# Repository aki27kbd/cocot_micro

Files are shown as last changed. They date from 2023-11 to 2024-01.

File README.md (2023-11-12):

# cocot_micro

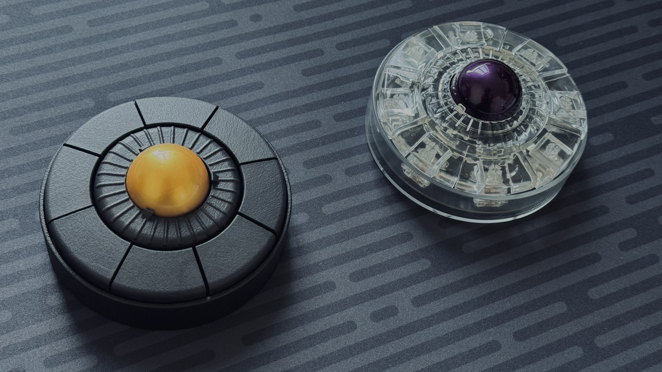
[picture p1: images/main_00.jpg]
cocot_micro_main00


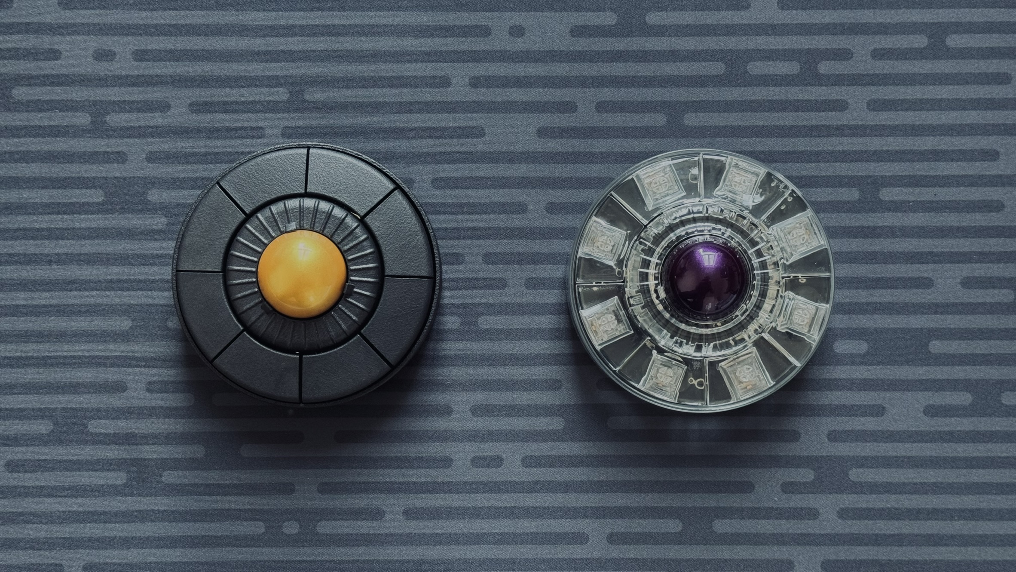
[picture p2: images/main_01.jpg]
cocot_micro_main01


cocot micro is a DIY trackball composed of mechanical keyboard components. You can use it as a trackball mouse as well as a macro pad with a pointing device.

### Features
- Customizable 8 buttons like mouse left/center/right clicks or any other keycodes
- Symmetrical design which enables you to use either right/left hands you prefer to
- With a ring encoder around the ball, you can assign keys like volume up/down or scroll up/down
- Smooth bearing rollers supports the ball
- You can swap a 34mm ball with a 40mm ball with optional ball base/ballcover parts
- With vial-compatible firmware, you can easily customize your own keymaps
- The center of PCB can be cut off and used for a MCU & sensor module with which you can create your own trackball mouse

### Configuration
- Keyboard Maintainer: [aki27kbd](https://github.com/aki27kbd) [@aki27kbd](https://twitter.com/aki27kbd)
- Hardware Supported: cocot micro PCB, RP2040 on board
- Hardware Availability: [cocotkeebs](https://cocotkeebs.com)

Build Guide [JP](doc/buildguide.md) / [EN](doc/buildguide_en.md)

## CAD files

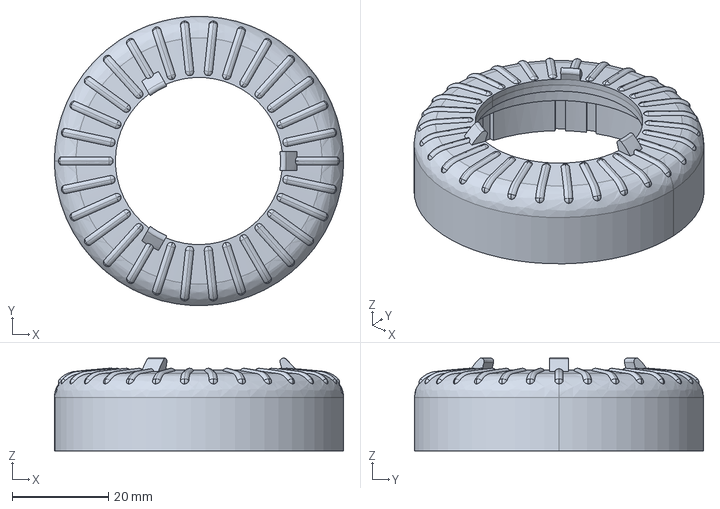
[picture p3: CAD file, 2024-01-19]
hardware/cocot_micro_BallCover_34mm_ClearResin.stp
60.0 x 59.9 x 19.2 mm

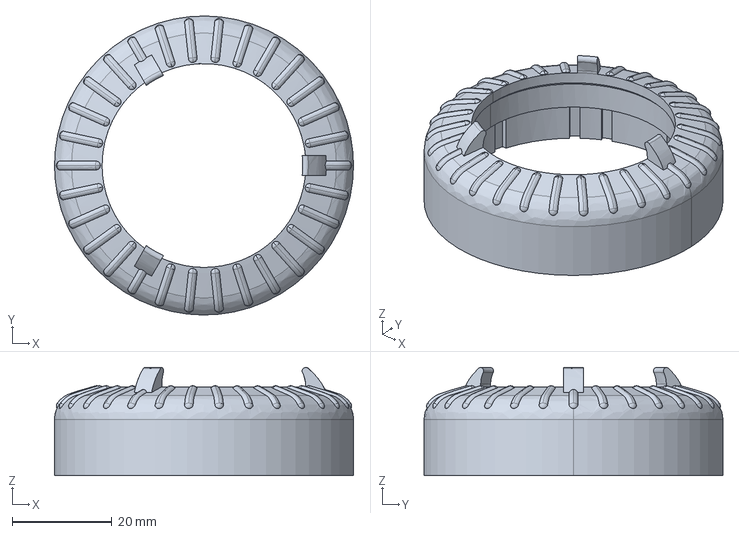
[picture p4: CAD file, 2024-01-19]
hardware/cocot_micro_BallCover_40mm_ClearResin.stp
60.0 x 60.0 x 21.7 mm

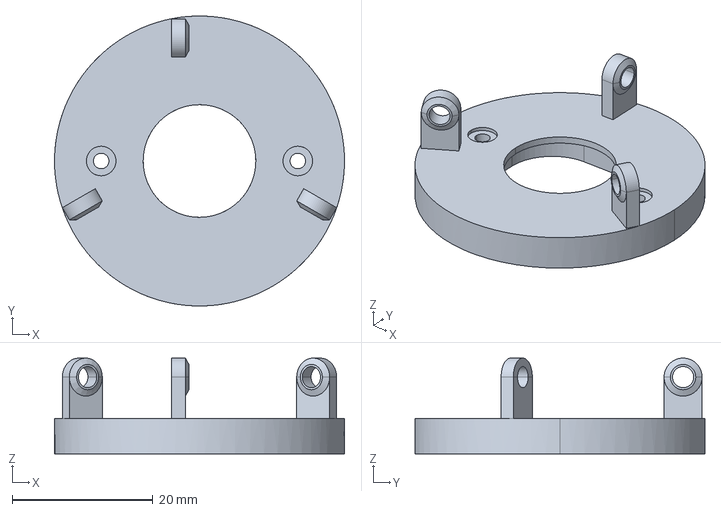
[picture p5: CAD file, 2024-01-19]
hardware/BallBase_40mm_Bearing.stp
41.2 x 41.2 x 13.6 mm

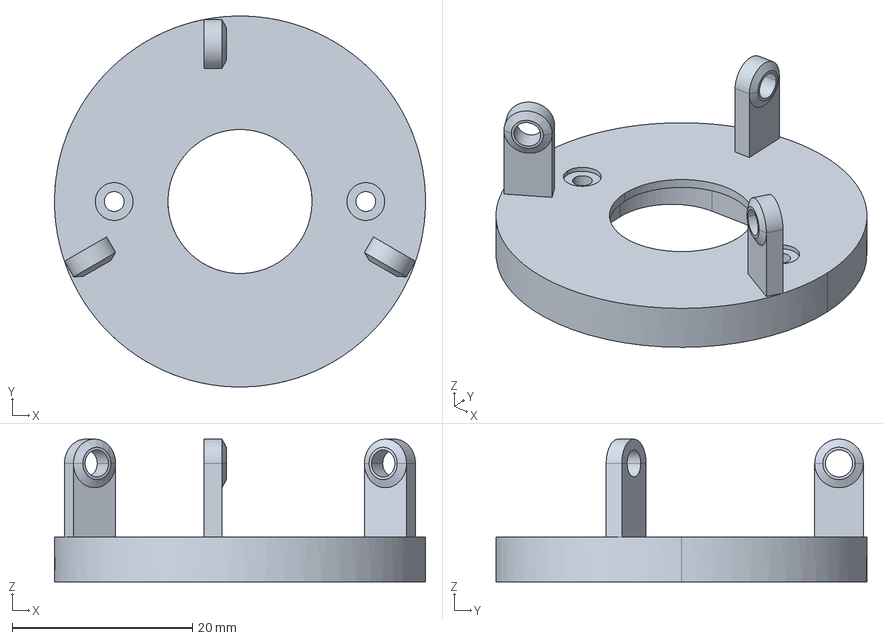
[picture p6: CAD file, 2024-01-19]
hardware/BallBase_34mm_Bearing.stp
41.2 x 41.2 x 15.9 mm

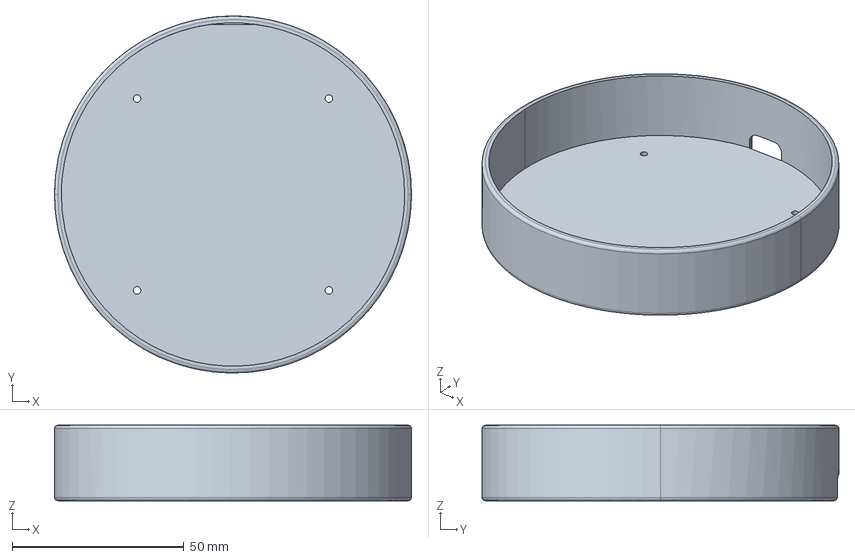
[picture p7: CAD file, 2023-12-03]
hardware/cocot_micro_tray_mount_case.stp
104.0 x 104.0 x 22.0 mm

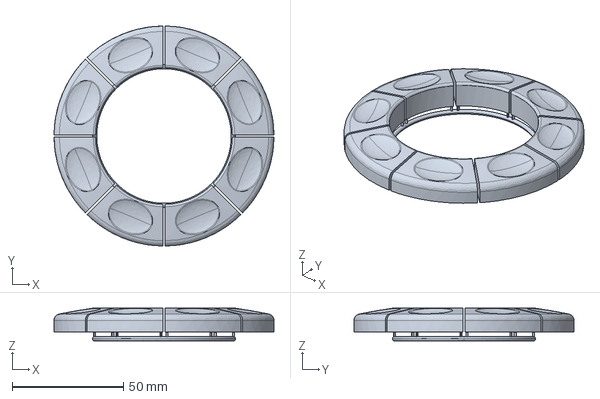
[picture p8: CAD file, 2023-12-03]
hardware/cocot_micro_keycap_scooped_union.stp
99.0 x 99.0 x 14.8 mm

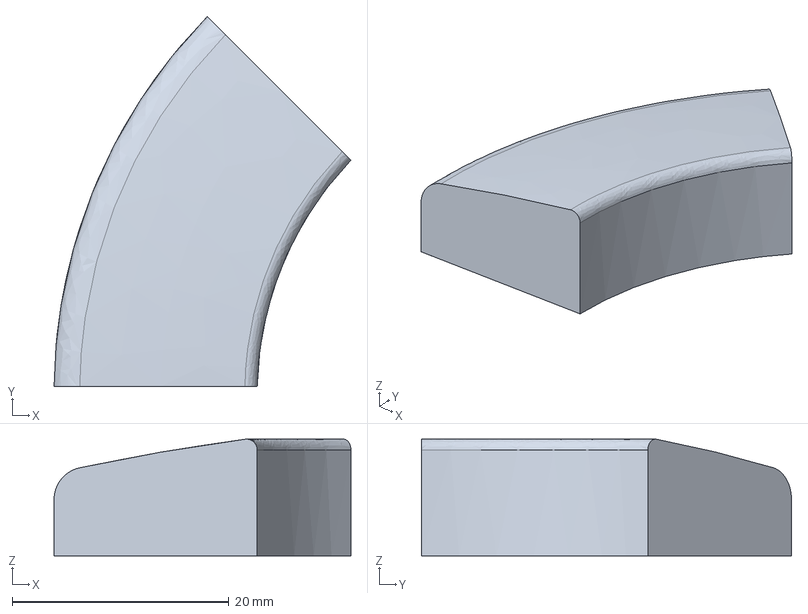
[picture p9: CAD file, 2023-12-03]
hardware/cocot_micro_keycap_normal.stp
27.4 x 34.1 x 10.8 mm

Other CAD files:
hardware/cocot_micro_BallCover_40mm_MJF.stp
hardware/cocot_micro_BallCover_34mm_MJF.stp
hardware/cocot_micro_keycap_normal_union.stp
hardware/cocot_micro_keycap_scooped.stp

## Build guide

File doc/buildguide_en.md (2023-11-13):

# Build Guide

cocot_micro_main00

This page is the build guide for cocot micro.

cocot micro is a DIY trackball composed of mechanical keyboard components. You can use it as a trackball mouse as well as a macro pad with a pointing device.

## Parts
### What's included

|Name|Number|Remarks|
|---|---|---|
|PCB|1||
|Mouse Sensor (PMW3360)|1||
|Ring Encoder (PER601)|1||
|M3 Screw 10mm|3||
|M3 Nut|3|
|M2 Screw 8mm|2|
|M2 Nut|2||
|M2 Screw 3mm|8|
|M2 Spacer 4mm|4||
|Rubber Feet|4||
|3D Printed Ball Base|1||
|3D Printed Ball Cover|1||
|3D Printed Keycaps|8|Optional|
|3D Printed Case|1|Optional|

### What's not included

|Name|Number|Remarks|
|---|---|---|
|MX Switch|8||
|34mm Trackball|1||
|USB-TypeC Cable|1||

## Assembly
### Parts Confirmation

  First, please make sure that you have all the parts listed in the kit accessories.  
  Please start assembling after you have prepared the "other necessary items" as described above.

  - If PCBs come with tabs, break off the tabs and lightly file the cut surfaces.
  - If you are not using a 3D printed case, paint the sides of the PCB black with an permanent marker to make it look better.

### Mouse Sensor

  Place the mouse sensor (PMW3360) on the bottom side of the PCB in the orientation shown in the photo, and solder from the top. Be careful to align the ● mark on the silk with the ● mark on the board.    
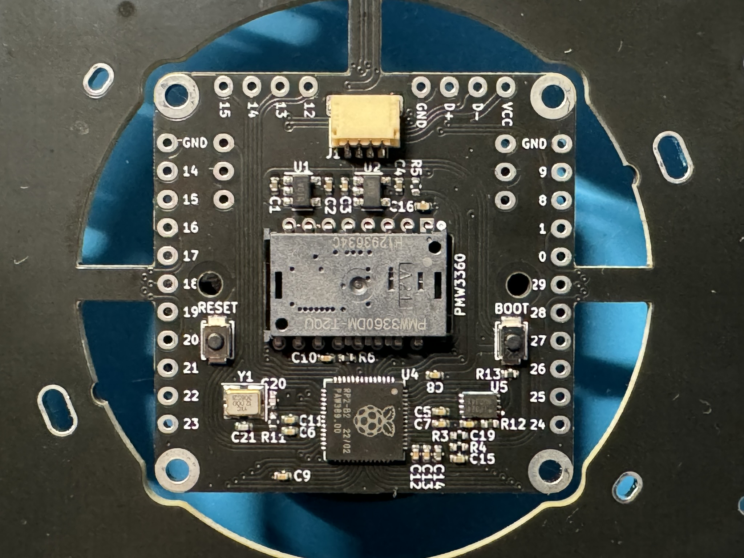
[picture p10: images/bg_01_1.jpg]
cocot_micro_bg_01_1
  

  Fix the sensor with masking tape so they do not move while soldering. Solder the 16 legs from the top side.  
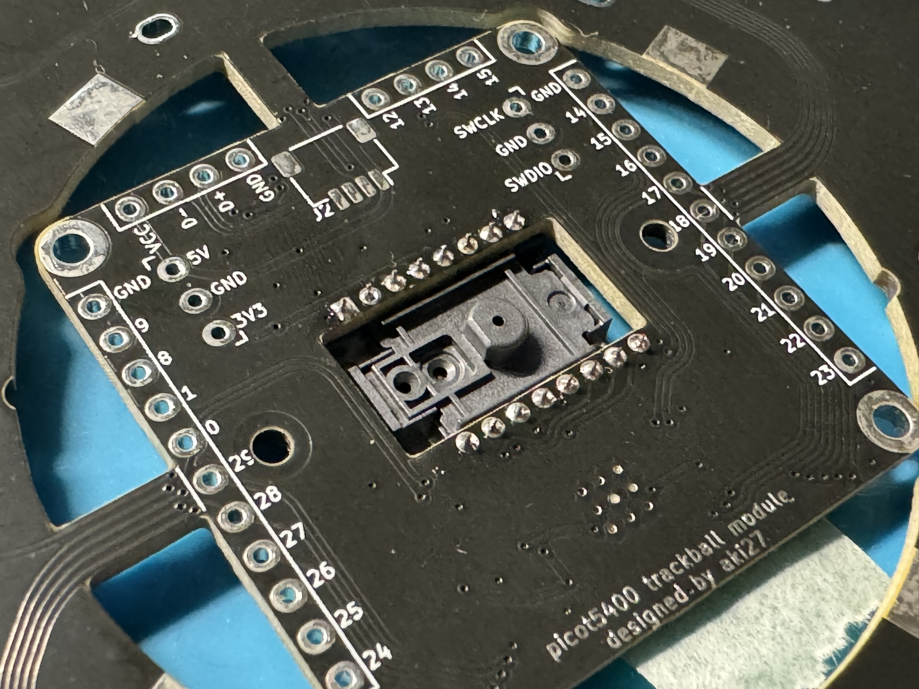
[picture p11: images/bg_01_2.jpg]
cocot_micro_bg_01_2
  

  Remove the kapton tape on the sensor and put lens.
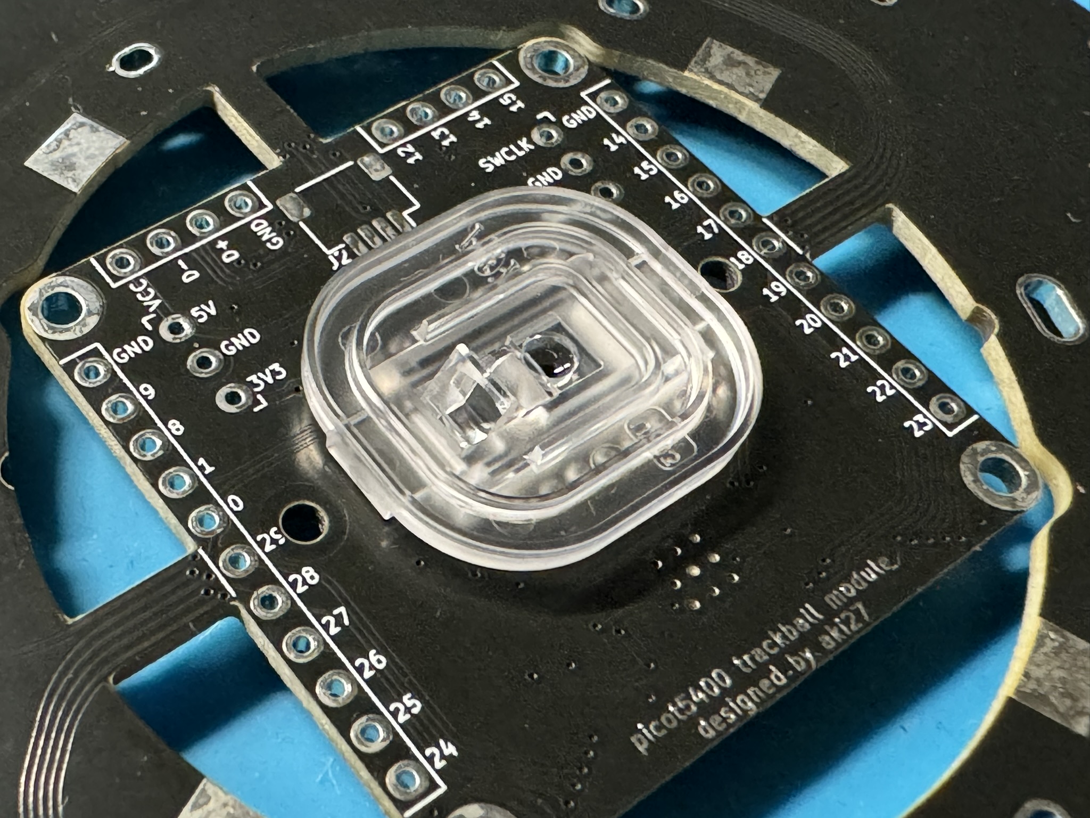
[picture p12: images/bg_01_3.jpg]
cocot_micro_bg_01_3
  

### Ball Base Assembly

  Fix the bearing roller with the bearing rollers, M3 screws, and M3 nuts in the orientation shown in the photo. Of the two sides of the three pillars supporting the bearing, it is the side with protrusions that the bearing is fixed to and the flat side that the nut touches.
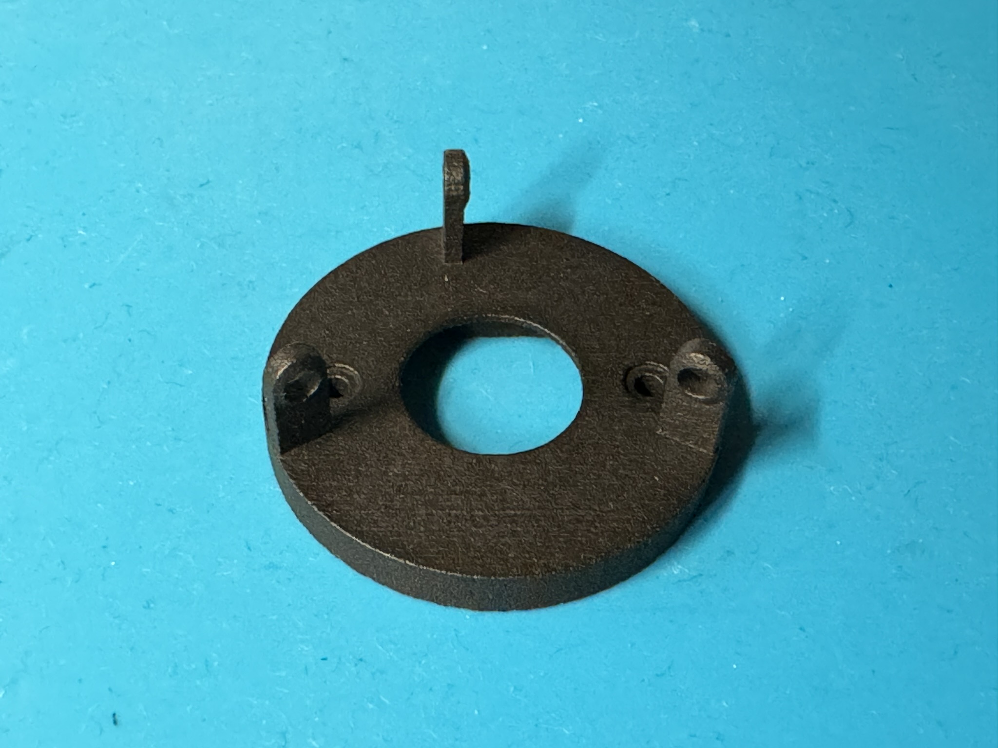
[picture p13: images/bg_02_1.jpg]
cocot_micro_bg_02_1
  

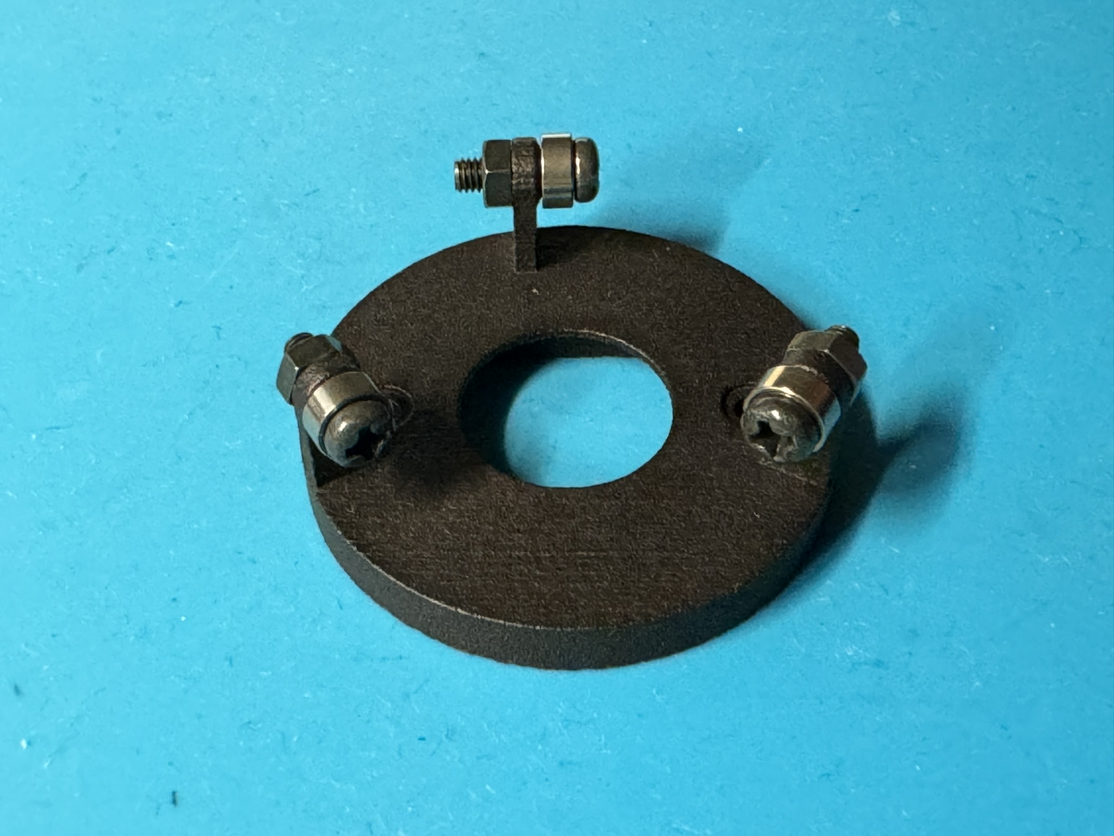
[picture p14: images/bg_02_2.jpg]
cocot_micro_bg_02_2
  

  Place the ball base on the PCB with the mouse sensor fixed and the lens attached. Fix with M2 8mm screws from the top side and nuts from the bottom side.
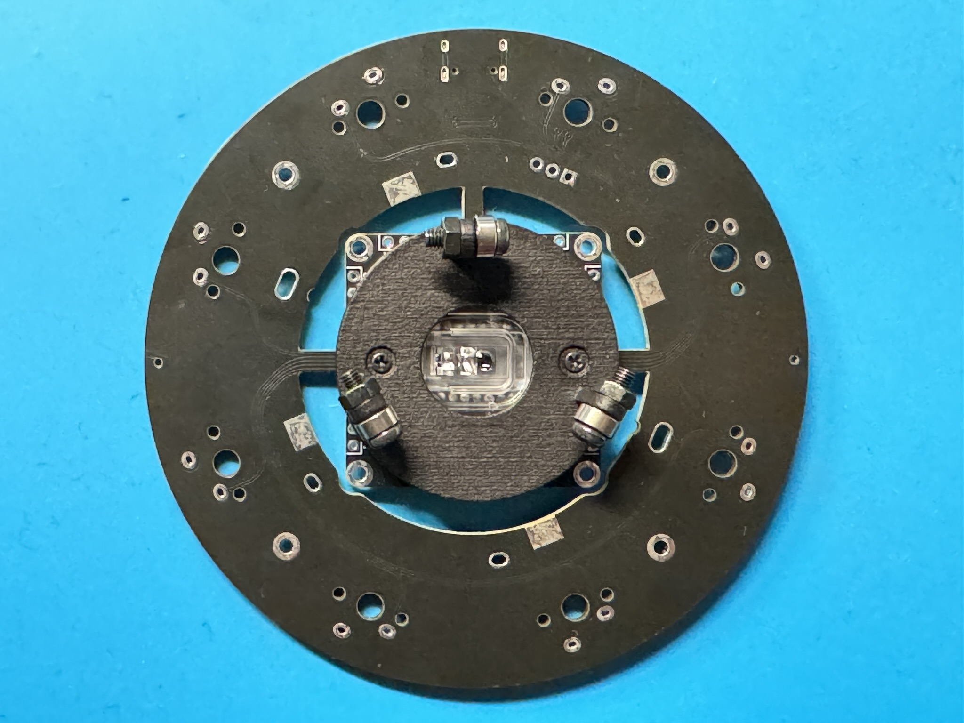
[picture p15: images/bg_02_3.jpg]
cocot_micro_bg_02_3
  

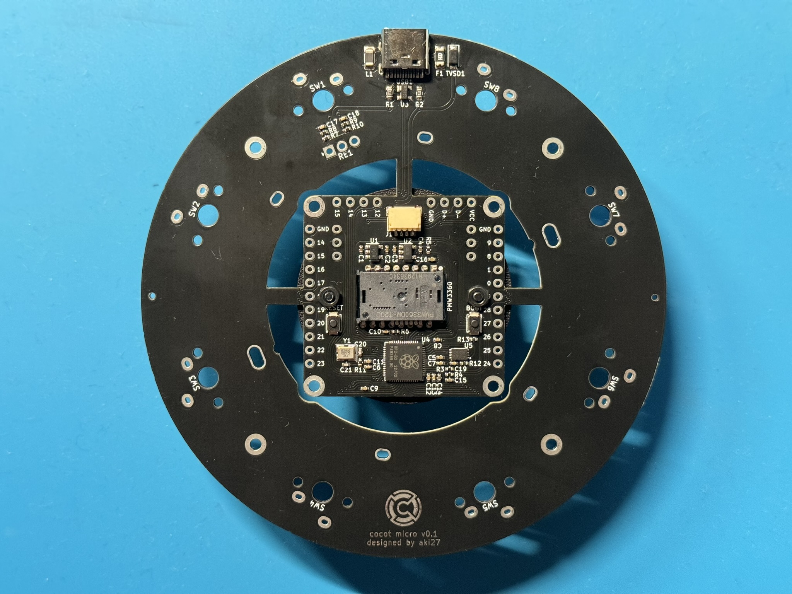
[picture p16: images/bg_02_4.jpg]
cocot_micro_bg_02_4
  

### Ring Encoder

  Insert the ring encoder from the top of the PCB and solder on the bottom side.  
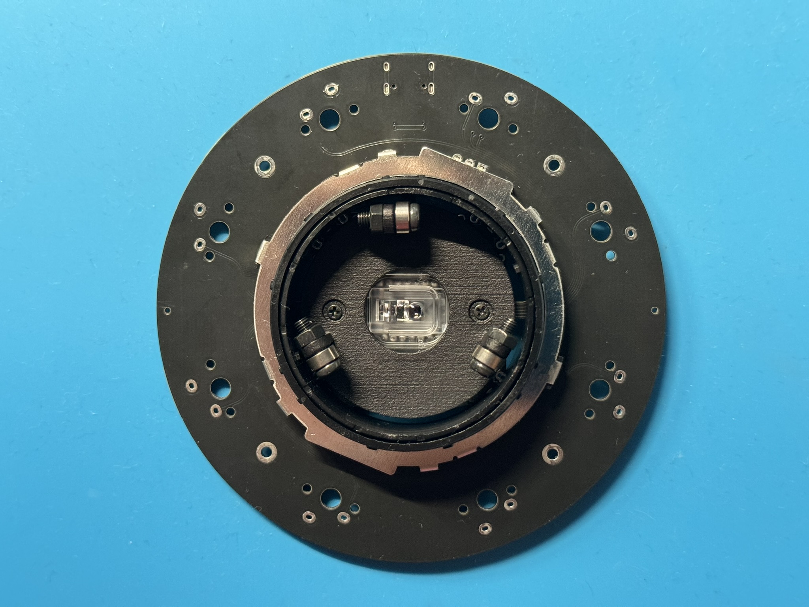
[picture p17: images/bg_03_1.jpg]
cocot_micro_bg_03_1
  

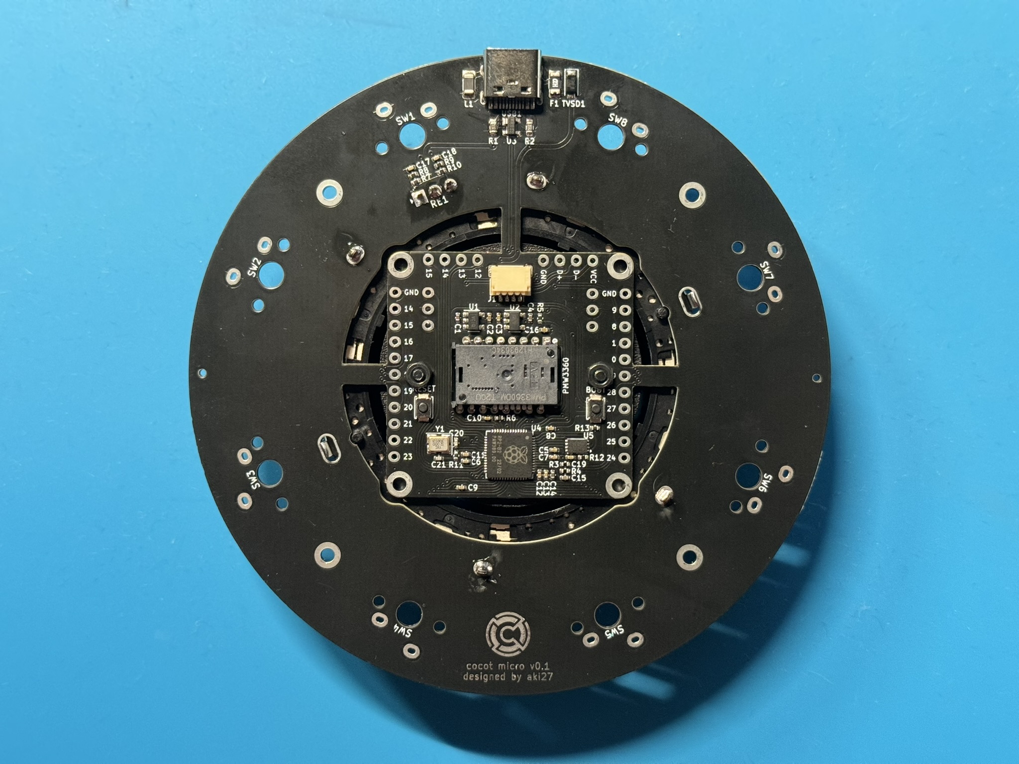
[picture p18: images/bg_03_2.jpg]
cocot_micro_bg_03_2
  

### Key Switch

  Insert the 8 key switches from the top of the PCB and solder 2 pins for each switch. Note the orientation of the switches so that they are on the top of the PCB.
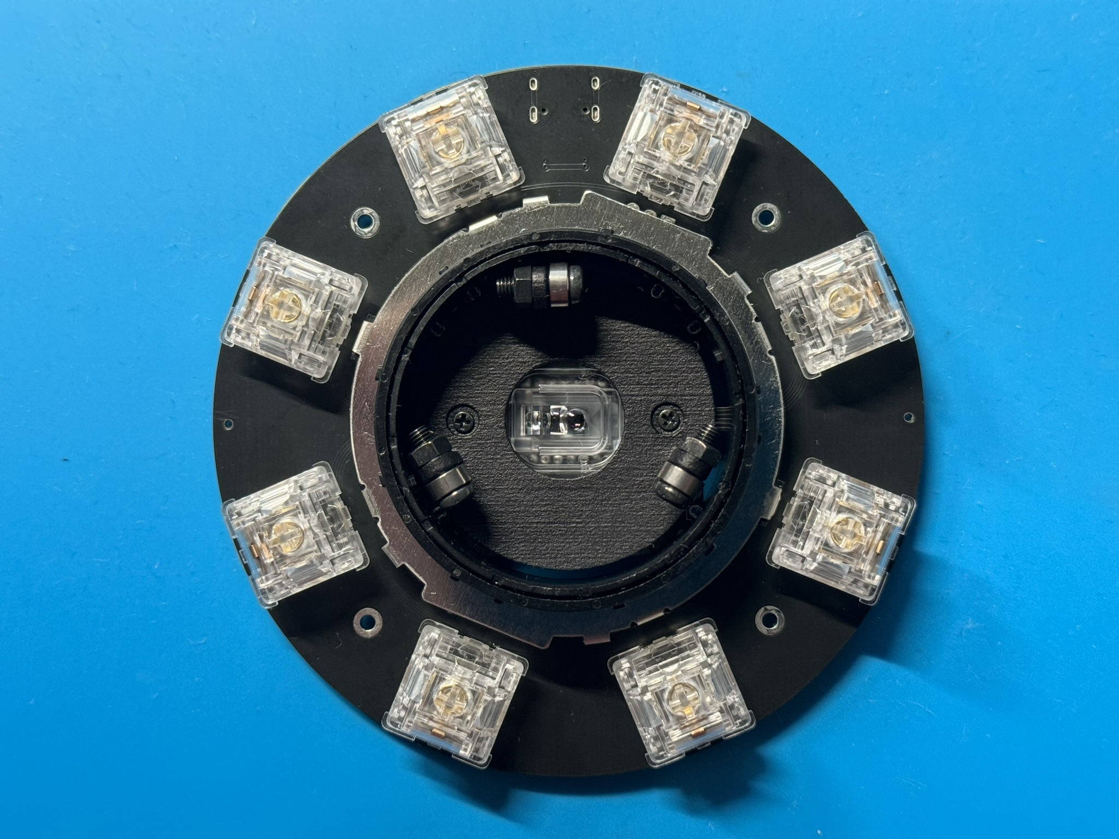
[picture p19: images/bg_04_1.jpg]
cocot_micro_bg_04_1
  

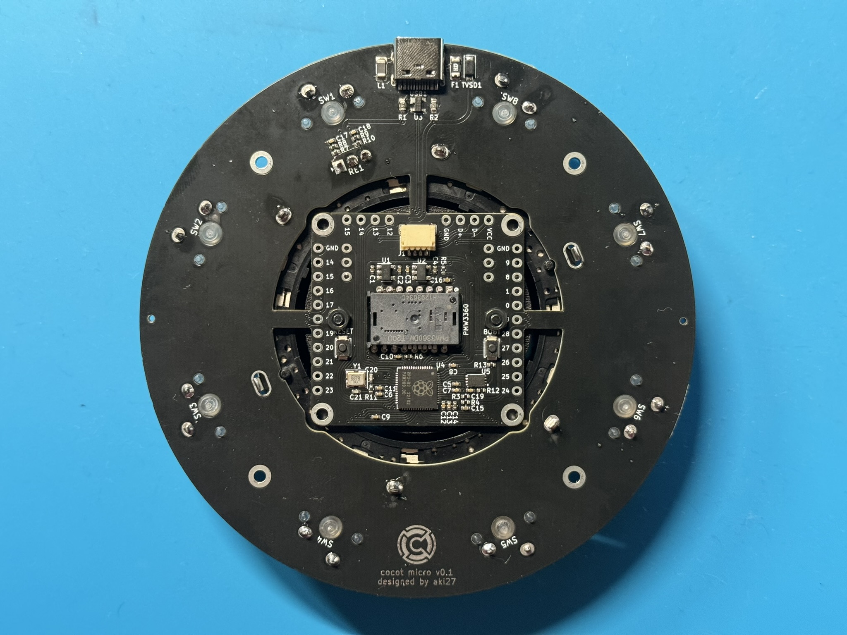
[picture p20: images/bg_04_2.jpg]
cocot_micro_bg_04_2
  

### Assembly

  Fix the tray case (or bottom plate) and PCB using 3mm screws and 4mm spacers.  
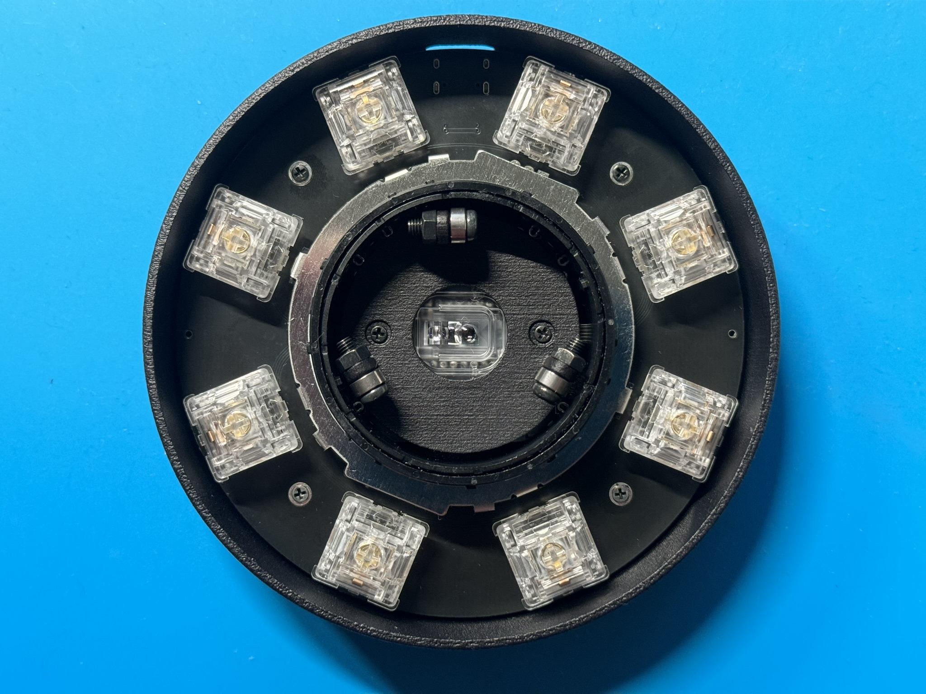
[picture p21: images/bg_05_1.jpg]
cocot_micro_bg_05_1
  

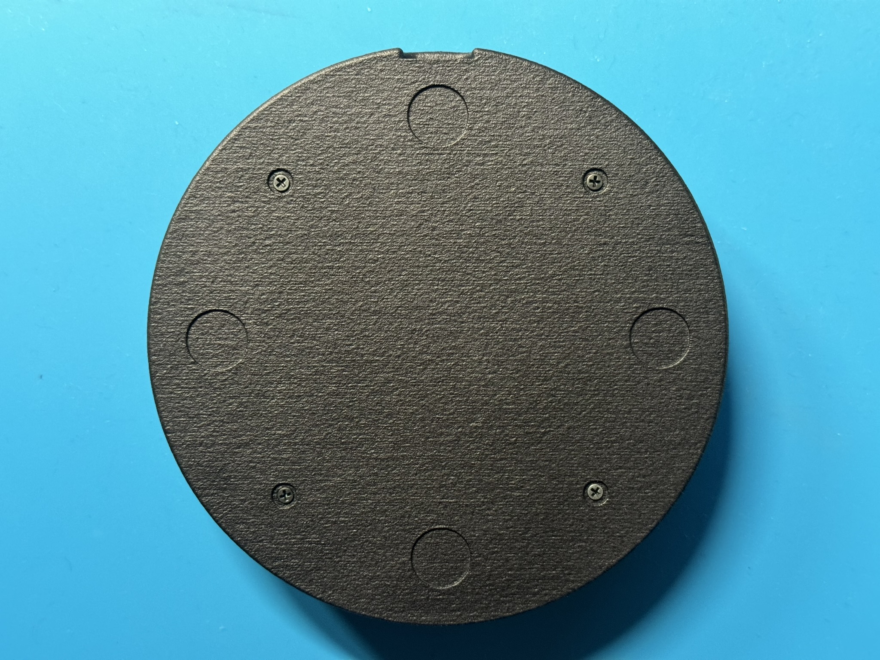
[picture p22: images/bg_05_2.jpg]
cocot_micro_bg_05_2
  

  Attach rubber feet in 4 places on the bottom side.
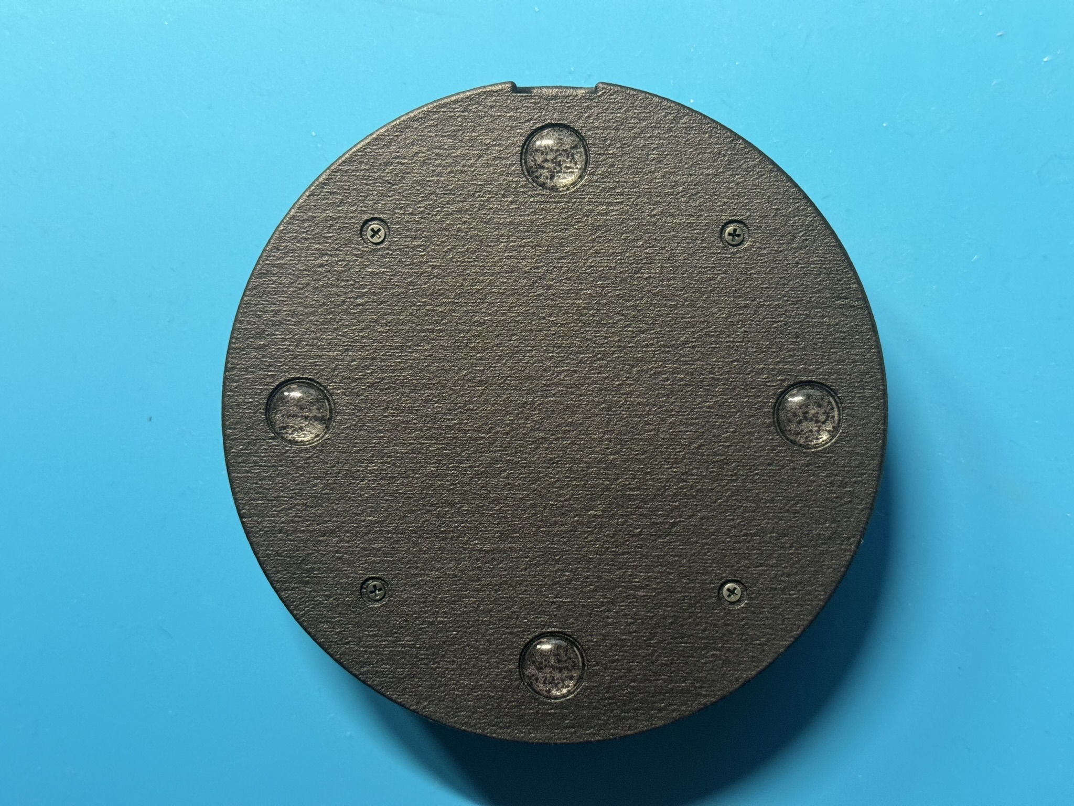
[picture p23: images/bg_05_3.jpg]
cocot_micro_bg_05_3
  

  Attach the ball cover to the ring encoder. If it is loose, tape or otherwise secure it on the inside.
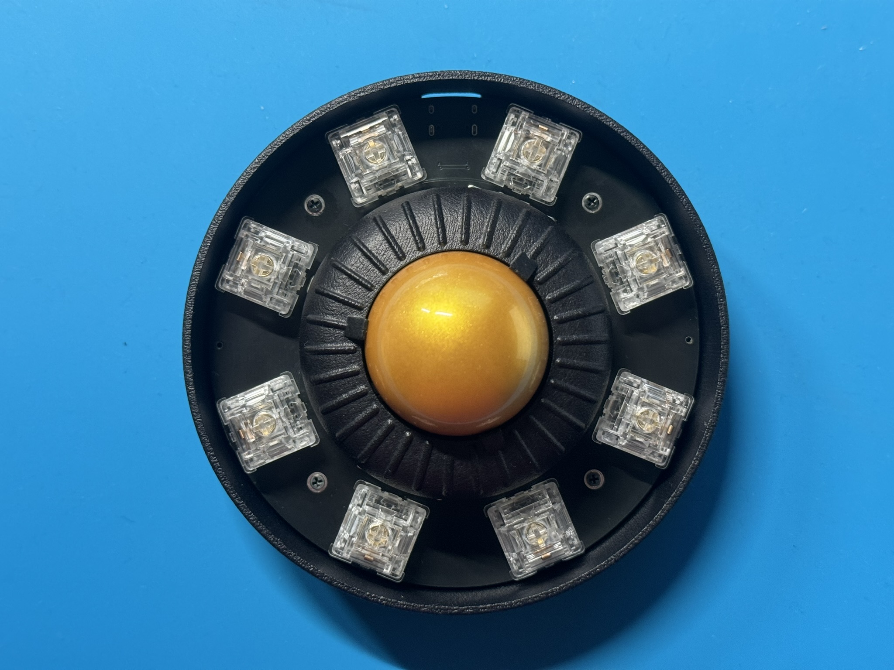
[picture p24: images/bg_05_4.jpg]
cocot_micro_bg_05_4
  

  Attach the keycaps. If the 3D printed Keycaps are loose, put plastic wrap or other thin film on the stem of key switch to prevent it from falling out.
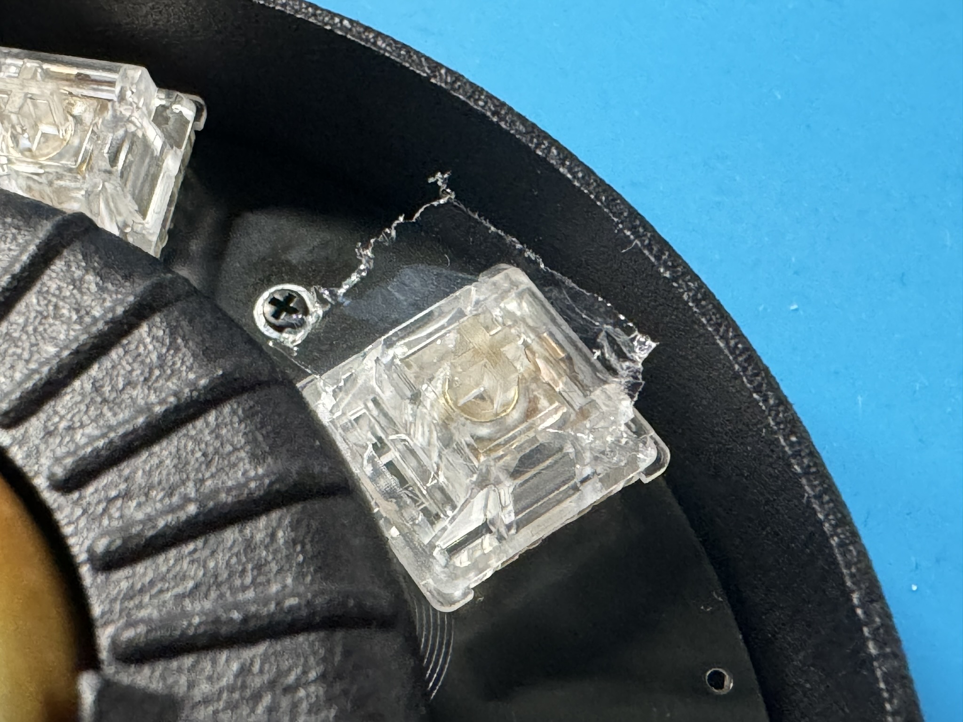
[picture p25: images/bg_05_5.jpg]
cocot_micro_bg_05_5
  

  Attach the ball and complete.
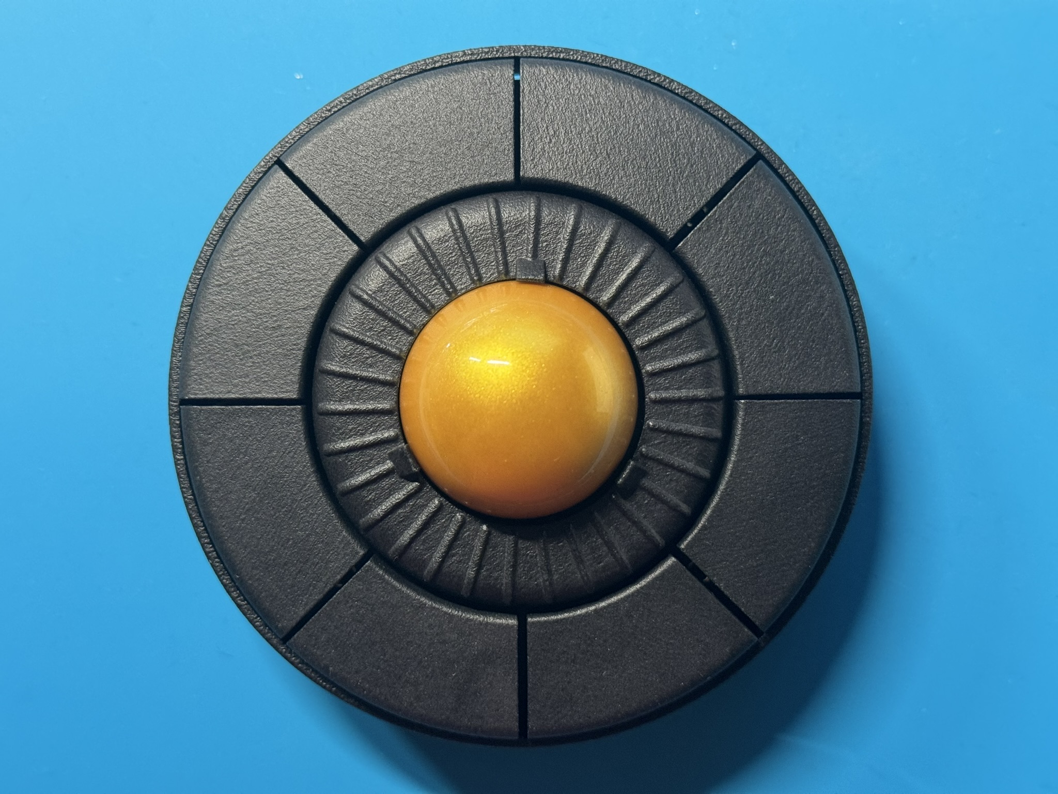
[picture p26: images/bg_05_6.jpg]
cocot_micro_bg_05_6
  

## Firmware

  PCB is delivered with the default firm flashed. If you wish to write your own firm, please follow the instructions below.

  - Press the RESET button while holding down the BOOT button on the bottom to enter boot loader mode.
  - In that state, drag and drop a [.uf2](https://github.com/aki27kbd/cocot_micro/blob/main/firmware/aki27_cocot_micro_auto_mouse.uf2) The farm is written by dragging and dropping the file.

  Keymap is editable from [vial](https://vial.rocks/).  

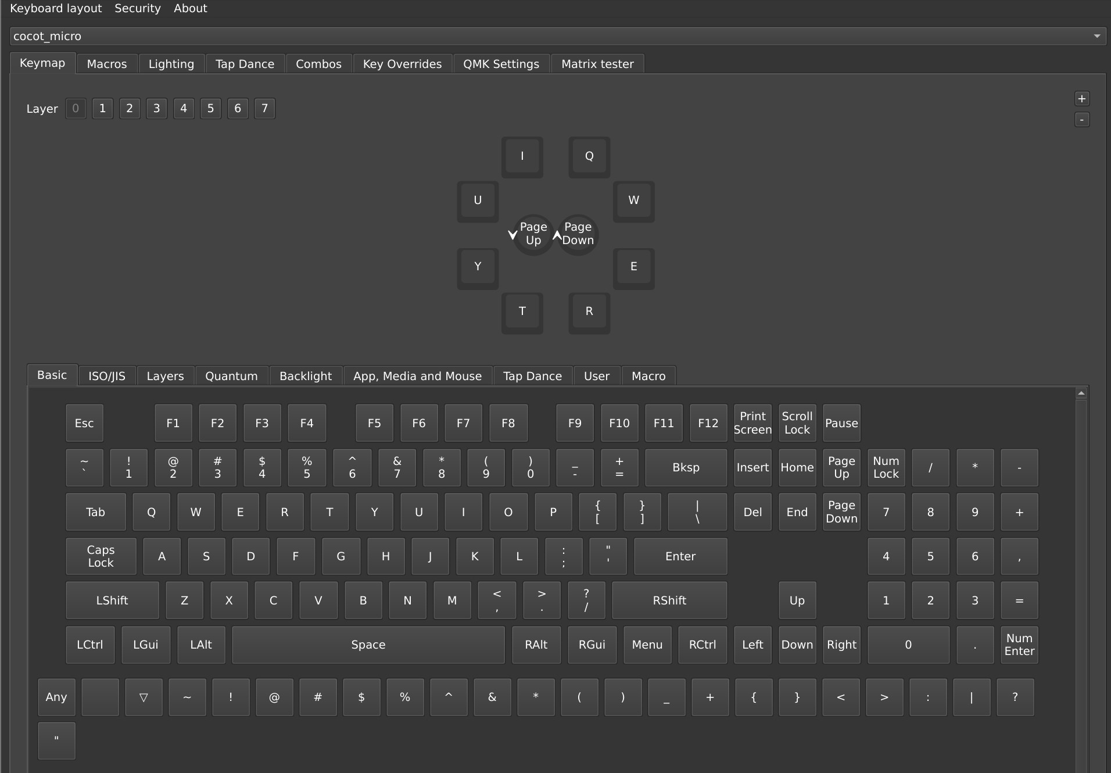
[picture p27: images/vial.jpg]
vial
  

  Source code is available from [here](https://github.com/aki27kbd/vial-qmk/tree/vial/keyboards/aki27/cocot_micro).  

## Custom Keycodes

  Several custom key codes can be set for trackball operation.

  Keycode   |Description
  ---------|-----------
  `CPI_SW`  |Change the CPI of the trackball. With the default firmware, each press changes the CPI in the following order: 200 -> 400 -> 800 -> 1600 -> 3200 -> 200....
  `SCRL_SW` |Changes the sensitivity of the sensor in scroll mode. The higher the value, the smaller the amount of scrolling.
  `ROT_R15` |Turns the Y axis of the mouse sensor 15 degrees clockwise.
  `ROT_L15` |Rotate the Y axis of the mouse sensor 15 degrees counterclockwise.
  `SCRL_MO` |Enables scroll mode for as long as it is pressed.
  `SCRL_TO` |	Toggles between scroll mode and mouse mode each time it is pressed.
  `SCRL_IN` |Inverts the scroll direction.

  Custom key codes can be set in vial using the custom key code under the User tab.  
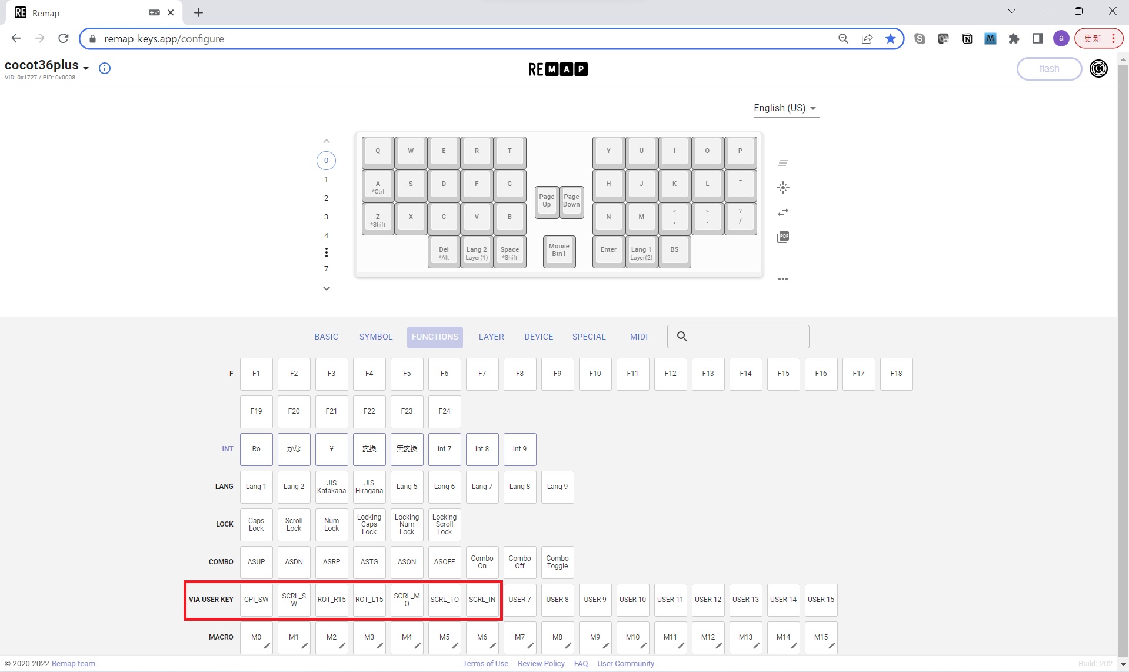
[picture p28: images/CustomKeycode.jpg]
CustomKeycode_rev
  

## Notes
If you have any problems, please contact us at [Twitter account](https://twitter.com/aki27kbd).

Also, it would be very encouraging if you could upload the completed photos to social networking sites. (If you don't feel comfortable uploading your photos, you can send them directly to us via DM.)

The hashtag is #cocot_micro.

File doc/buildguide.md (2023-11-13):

# Build Guide

cocot_micro_main00

cocot microのビルドガイドです。

cocot microは自作キーボードのエッセンスからデザインされた自作トラックボールキットです。トラックボールマウスとしてはもちろん、ポインティングデバイスが付属したマクロパッドとして活用することも可能です。

## 部品
### キット付属品

|名前|数|備考|
|---|---|---|
|PCB|1枚||
|マウスセンサー（PMW3360）|1||
|リングエンコーダ（PER601）|1||
|M3ねじ 10mm|3||
|M3ナット|3|
|M2ねじ 8mm|2|
|M2ナット|2||
|M2ねじ 3mm|8|
|M2スペーサー 4mm|4||
|ゴム脚|4||
|3Dプリントボールベース|1||
|3Dプリントボールカバー|1||
|3Dプリントキーキャップ|8|オプション|
|3Dプリントケース|1|オプション|

### キット以外に必要なもの

|名前|数|備考|
|---|---|---|
|MX互換キースイッチ|8||
|34mmボール|1||
|USB-TypeCケーブル|1||

## 組み立て
### 部品確認

  まずはキット付属品に記載されたパーツが揃っているか確認ください。  
  その他上述の「キット以外に必要なもの」を揃えた上で組み立てに取り掛かってください。

  - タブ付きPCBの場合にはタブを割って切り離し、切断面を軽くヤスリがけしてください。
  - 3Dプリントケースを用いない場合、PCBの側面を油性マジックなどで黒く塗ると見栄えが良くなります。

### マウスセンサー

  マウスセンサー（PMW3360）を基板裏面から写真の向きに設置し、表面からはんだ付けを行います。シルクの●印と基板の●　印の位置が合うように注意してください。  
  cocot_micro_bg_01_1

  センサーの脚がしっかり奥まで入った状態で、浮かないようにマスキングテープなどで固定します。表側から16本の脚をはんだ付けします。  
  cocot_micro_bg_01_2

  センサーに貼られているテープを剥がし、表面からレンズを付けます。
  cocot_micro_bg_01_3

### ボールベース組み立て

  ボールベースにベアリングローラーを固定します。写真の向きに合わせてベアリングローラー、M3ネジ、M3ナットで固定します。ベアリングを支持する3本の柱の両サイドのうち、ベアリングが固定されるのが突起のある面、ナットが触れるのが平坦な面になります。
  cocot_micro_bg_02_1

  cocot_micro_bg_02_2

  マウスセンサーを固定しレンズを装着したPCBにボールベースを被せます。表面からM2 8mmネジ、裏面からナットで固定します。
  cocot_micro_bg_02_3

  cocot_micro_bg_02_4

### リングエンコーダ

  リングエンコーダをPCB表面から差し込み、裏面の3か所はんだ付けを行います。  
  cocot_micro_bg_03_1

  cocot_micro_bg_03_2

### キースイッチ

  8個のキースイッチをPCB表面から差し込み、各スイッチ2か所はんだ付けを行います。スイッチが基板の表面に来るように向きに注意してください。
  cocot_micro_bg_04_1

  cocot_micro_bg_04_2

### 組み立て

  トレイケース（ボトムプレート）とPCBを3mmネジと4mmスペーサーを用いて固定します。  
  cocot_micro_bg_05_1

  cocot_micro_bg_05_2

  裏面4か所にゴム脚を貼り付けます。
  cocot_micro_bg_05_3

  リングエンコーダ―にボールカバーを取り付けます。緩い場合は内側にテープなどを貼り固定します。
  cocot_micro_bg_05_4

  キーキャップをつけます。付属の3Dプリントキーキャップが緩い場合は、ラップなど薄いフィルムを被せて抜けにくくしてください。
  cocot_micro_bg_05_5

  ボールを付けて完成です。
  cocot_micro_bg_05_6

## ファームウェア

デフォルトのファームが書き込まれた状態でお届けしています。ご自分でファームを書き込む場合、下記手順の通り実行してください。

  - 裏面のBOOTボタンを押しながらRESETボタンを押し、ブートローダーモードに入ります。
  - その状態でRPI-RP2というドライブに[.uf2](https://github.com/aki27kbd/cocot_micro/blob/main/firmware/aki27_cocot_micro_auto_mouse.uf2)ファイルをドラッグ&ドロップすることでファームが書き込まれます。

キーマップは[vial](https://vial.rocks/)から更新可能です。  
トラックボール、LED含めて上記.uf2ファイルで確認いただけます。

vial

ソースコードは[こちら](https://github.com/aki27kbd/vial-qmk/tree/vial/keyboards/aki27/cocot_micro)を参照ください。  
また、VIA用のjsonファイルは[こちら](https://github.com/aki27kbd/cocot_micro/blob/main/firmware/cocot_micro_via.json)を参照ください。

## カスタムキーコード

  トラックボールの操作に関していくつかカスタムキーコードを設定することが可能です。

  Keycode   |Description
  ---------|-----------
  `CPI_SW`  |トラックボールのCPIを変更します。デフォルトのファームウェアでは、押すたびに200→400→800→1600→3200→200…という順番でCPIが変わります。
  `SCRL_SW` |スクロールモードにおけるセンサーの感度を変更します。数値が大きいほどスクロール量が小さくなります。
  `ROT_R15` |マウスセンサーのＹ軸を時計回りに15度回転させます。
  `ROT_L15` |マウスセンサーのＹ軸を反時計回りに15度回転させます。
  `SCRL_MO` |押されている間スクロールモードになります。（デフォルトファームではレイヤー4でのみ有効）
  `SCRL_TO` |押すたびにスクロールモードとマウスモードを切り替えます。（デフォルトファームでは無効）
  `SCRL_IN` |スクロール方向を反転させます。（デフォルトファームでは無効）

  vialでカスタムキーコードを設定する場合はUserタブ下のカスタムキーコードを用いて設定することが可能です。  
  CustomKeycode_rev

## 終わりに
何かトラブルがあれば[Twitterアカウント](https://twitter.com/aki27kbd)までご連絡ください。

また、完成写真をSNSにアップいただけるととても励みになります。（アップするのがはばかられる方はDMで直接送りつけていただいても構いません。）

ハッシュタグは #cocot_micro です。

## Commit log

2023-12-03 add keycap 3d data
    [cocot_micro_keycap_normal.stp, cocot_micro_keycap_normal_union.stp, cocot_micro_keycap_scooped.stp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]
2023-12-03 add tray mount case data
    [cocot_micro_tray_mount_case.stp]
2024-01-19 add license
    [BallBase_34mm_Bearing.stp, BallBase_40mm_Bearing.stp, cocot_micro_BallCover_34mm_ClearResin.stp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]
